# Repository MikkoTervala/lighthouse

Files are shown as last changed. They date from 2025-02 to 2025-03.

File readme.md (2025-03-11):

# Lighthouse

### Lighthouse for Family Connection

#### See also: [lighthouse-firmware](https://github.com/MikkoTervala/lighthouse-firmware)

**Lighthouse** is a connected smart decoration that synchronizes over the internet to let your family know when you're home.

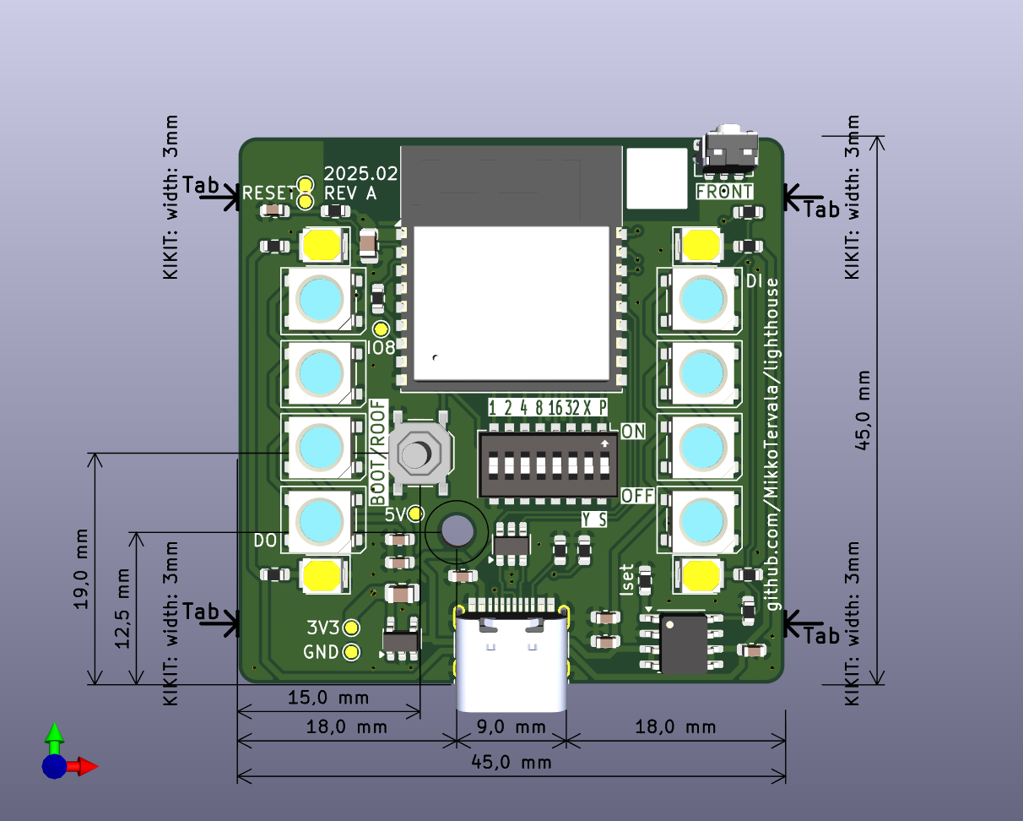
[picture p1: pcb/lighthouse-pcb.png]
Lighthouse PCB


## Views and Schematics

- **[🌐 Schematic View](https://kicanvas.org/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)**

- **[🌐 Board Layout](https://kicanvas.org/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)**

- **[🌐 Interactive 3D View](https://3dviewer.net/index.html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)**

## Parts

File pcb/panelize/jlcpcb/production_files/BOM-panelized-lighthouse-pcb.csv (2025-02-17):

Comment | Designator | Footprint | LCSC | Quantity
1µF | C1 | C_0603_1608Metric | C15849 | 1
10µf | C3,C6 | C_0805_2012Metric | C15850 | 2
USB_C_Receptacle_USB2.0 | J1 | USB_C_Receptacle_HRO_TYPE-C-31-M-12 | C165948 | 1
220nf | C10,C7 | C_0603_1608Metric | C21120 | 2
2 | R10,R7,R8,R9 | R_0603_1608Metric | C22977 | 4
5.1k | R5,R6 | R_0603_1608Metric | C23186 | 2
2.2µf | C4,C5,C8,C9 | C_0603_1608Metric | C23630 | 4
10k | R1,R13,R2,R3 | R_0603_1608Metric | C25804 | 4
WS2812B | D11,D12,D13,D2,D3,D4,D5,D6 | LED_WS2812B_PLCC4_5.0x5.0mm_P3.2mm | C2874885 | 8
ESP32-C3-WROOM-02 | U1 | ESP32-C3-WROOM-02 | C2934560 | 1
BOOT/ROOF | SW1 | SW_Push_1P1T_XKB_TS-1187A | C318885 | 1
SW_DIP_x08 | SW4 | SW_DIP_SPSTx08_Slide_Copal_CHS-08A_W5.08mm_P1.27mm_JPin | C3293147 | 1
CN5711 | U2 | SOIC-8-1EP_3.9x4.9mm_P1.27mm_EP2.41x3.3mm | C35634 | 1
3k | R11 | R_0603_1608Metric | C4211 | 1
AP2112K-3.3 | U3 | SOT-23-5 | C51118 | 1
FRONT | SW3 | SW_Push_1P1T-MP_NO_Horizontal_Alps_SKRTLAE010 | C561509 | 1
LED 0.5W 3000k | D10,D7,D8,D9 | LED_PLCC_2835 | C694723 | 4
USBLC6-2SC6 | U4 | SOT-23-6 | C7519 | 1

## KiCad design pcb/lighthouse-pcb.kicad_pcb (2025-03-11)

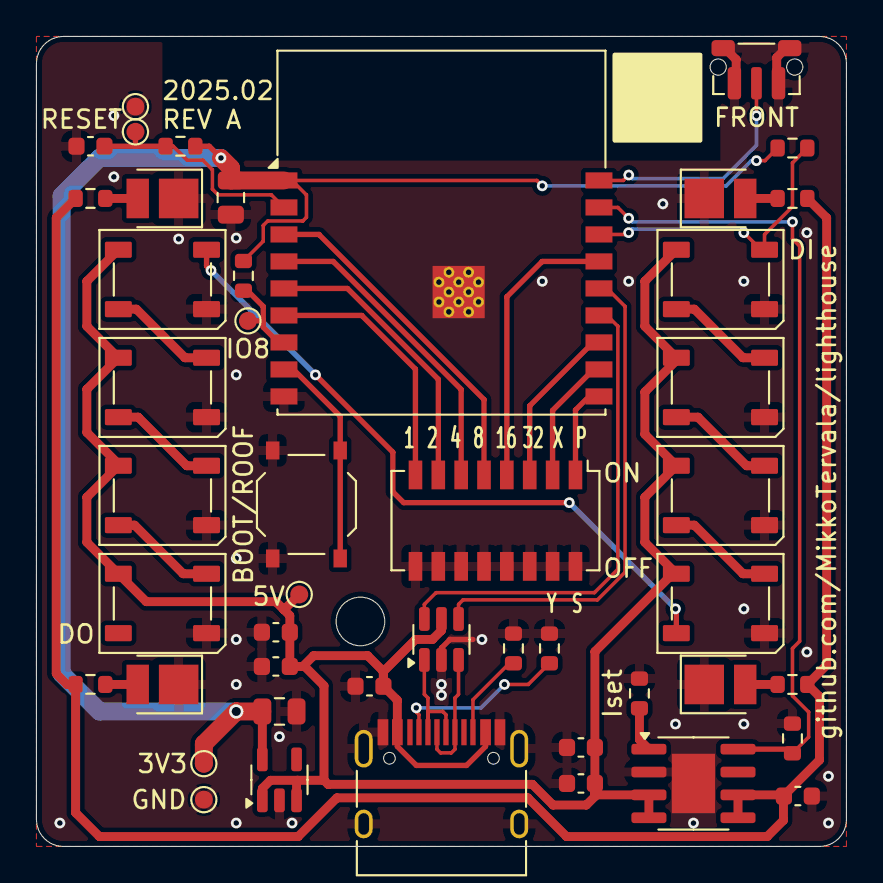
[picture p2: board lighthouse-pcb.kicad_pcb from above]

Board: 2 copper layers, 45.0 x 45.0 mm, 51 parts (0 on the bottom side), 36 nets.

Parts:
C1: 1µF; C_0603_1608Metric
C3, C6: 10µf; C_0805_2012Metric
C4, C5, C8, C9: 2.2µf; C_0603_1608Metric
C7, C10: 220nf; C_0603_1608Metric
D2, D3, D4, D5, D6, D11, D12, D13: WS2812B; LED_WS2812B_PLCC4_5.0x5.0mm_P3.2mm
D7, D8, D9, D10: LED 0.5W 3000k; LED_PLCC_2835
H4: MountingHole M2.5; MountingHole_2.7mm_M2.5
J1: USB_C_Receptacle_USB2.0; USB_C_Receptacle_HRO_TYPE-C-31-M-12
R1, R2, R3, R13: 10k; R_0603_1608Metric
R5, R6: 5.1k; R_0603_1608Metric
R7, R8, R9, R10: 2; R_0603_1608Metric
R11: 3k; R_0603_1608Metric
SW1: BOOT/ROOF; SW_Push_1P1T_XKB_TS-1187A
SW3: FRONT; SW_Push_1P1T-MP_NO_Horizontal_Alps_SKRTLAE010
SW4: SW_DIP_x08; SW_DIP_SPSTx08_Slide_Copal_CHS-08A_W5.08mm_P1.27mm_JPin
T1, T2, T3, T4: Tab
TP1, TP5: GND; TestPoint_Pad_D1.0mm
TP2: 3V3; TestPoint_Pad_D1.0mm
TP3: RESET; TestPoint_Pad_D1.0mm_no_court
TP4: IO8; TestPoint_Pad_D1.0mm
TP6: 5V; TestPoint_Pad_D1.0mm
U1: ESP32-C3-WROOM-02
U2: CN5711; SOIC-8-1EP_3.9x4.9mm_P1.27mm_EP2.41x3.3mm
U3: AP2112K-3.3; SOT-23-5
U4: USBLC6-2SC6; SOT-23-6

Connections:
+3V3: C3.1, C6.1, R1.1, R2.1, R3.2, TP2.1, U1.1 (3V3), U3.5 (VOUT)
+5V: C4.1, C5.1, C8.1, C9.1, C10.1, D2.1 (VDD), D3.1 (VDD), D4.1 (VDD), D5.1 (VDD), D6.1 (VDD), D11.1 (VDD), D12.1 (VDD), D13.1 (VDD), J1.A4 (VBUS), J1.A9 (VBUS), J1.B4 (VBUS), J1.B9 (VBUS), TP6.1, U2.3 (VCC), U2.4 (VCC), U3.1 (VIN), U3.3 (EN), U4.5 (VBUS)
/BOOT: SW1.2, U1.8 (IO9)
/D+: J1.A6 (D+), J1.B6 (D+), U4.3 (I/O2)
/D-: J1.A7 (D-), J1.B7 (D-), U4.1 (I/O1)
/EN: C1.2, R2.2, TP3.1, U1.2 (EN)
GND: C1.1, C3.2, C4.2, C5.2, C6.2, C7.2, C8.2, C9.2, C10.2, D2.3 (VSS), D3.3 (VSS), D4.3 (VSS), D5.3 (VSS), D6.3 (VSS), D7.1 (K), D8.1 (K), D9.1 (K), D10.1 (K), D11.3 (VSS), D12.3 (VSS), D13.3 (VSS), J1.A1 (GND), J1.A12 (GND), J1.B1 (GND), J1.B12 (GND), J1.S1 (SHIELD), R5.2, R6.1, R11.2, R13.2, SW1.1, SW3.1, SW3.MP (Shield), SW4.9, SW4.10, SW4.11, SW4.12, SW4.13, SW4.14, SW4.15, SW4.16, TP1.1, TP5.1, U1.9 (GND), U1.19 (GND), U2.2 (GND), U2.9 (PAD), U3.2 (GND), U4.2 (GND)
GPIO0: SW3.2, U1.18 (IO0)
GPIO1: R13.1, U1.17 (IO1), U2.8 (CE)
GPIO2: D3.4 (DIN), R3.1, U1.16 (IO2)
GPIO3: SW4.4, U1.15 (IO3)
GPIO4: SW4.5, U1.3 (IO4)
GPIO5: SW4.6, U1.4 (IO5)
GPIO6: SW4.7, U1.5 (IO6)
GPIO7: SW4.8, U1.6 (IO7)
GPIO8: R1.2, TP4.1, U1.7 (IO8)
GPIO10: SW4.1, U1.10 (IO10)
unnamed: C7.1, R7.2, R8.2, R9.2, R10.2, U2.5 (LED), U2.6 (LED)
unnamed: D2.4 (DIN), D6.2 (DOUT)
unnamed: D3.2 (DOUT), D4.4 (DIN)
unnamed: D4.2 (DOUT), D5.4 (DIN)
unnamed: D5.2 (DOUT), D6.4 (DIN)
unnamed: D7.2 (A), R7.1
unnamed: D8.2 (A), R8.1
unnamed: D9.2 (A), R9.1
unnamed: D10.2 (A), R10.1
unnamed: D2.2 (DOUT), D11.4 (DIN)
unnamed: D11.2 (DOUT), D12.4 (DIN)
unnamed: D12.2 (DOUT), D13.4 (DIN)
unnamed: J1.A5 (CC1), R5.1
unnamed: J1.B5 (CC2), R6.2
unnamed: R11.1, U2.1 (ISET)
RX/20: SW4.2, U1.11 (IO20/RXD)
TX/21: SW4.3, U1.12 (IO21/TXD)
USB_D+: U1.14 (IO19), U4.4 (I/O2)
USB_D-: U1.13 (IO18), U4.6 (I/O1)

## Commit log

2025-01-29 Add symbols and footprints
2025-01-29 Initial schematic
    [lighthouse-pcb.kicad_sch]
2025-02-08 Layout and two button design
    [lighthouse-pcb.kicad_pcb, lighthouse-pcb.kicad_sch]
2025-02-09 Add footprints
2025-02-09 REV A release
    [lighthouse-pcb.kicad_pcb, lighthouse-pcb.kicad_sch]
2025-02-11 Update GPIO0-2 schematic and layout
    [lighthouse-pcb.kicad_pcb, lighthouse-pcb.kicad_sch]
2025-02-11 Added missing JLC part numbers and fixed U3 missing trace
    [lighthouse-pcb.kicad_pcb, lighthouse-pcb.kicad_sch]
2025-02-11 Add datamatrix location
    [lighthouse-pcb.kicad_pcb]
2025-02-16 Remove identifier and tooling holes
    [lighthouse-pcb.kicad_pcb, lighthouse-pcb.kicad_sch]
2025-02-16 Remove tooling hole
    [lighthouse-pcb.kicad_pcb]
2025-02-17 Add information for panelization
    [lighthouse-pcb.kicad_pcb, lighthouse-pcb.kicad_sch]
2025-02-17 Add panelized production file
    [BOM-panelized-lighthouse-pcb.csv, panelized-lighthouse-pcb.kicad_pcb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]
2025-03-11 Cleanup measurements
    [lighthouse-pcb.kicad_pcb]
